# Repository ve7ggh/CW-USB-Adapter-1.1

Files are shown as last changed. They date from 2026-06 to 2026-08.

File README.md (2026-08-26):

# VE7GGH CW USB Adapter <!-- omit from toc -->

- [Instructions on How to Use](#instructions-on-how-to-use)
  - [Practice Software](#practice-software)
- [Project Structure](#project-structure)
- [Hardware](#hardware)
- [Firmware](#firmware)
- [Bootloader](#bootloader)
- [Building](#building)
  - [Hardware](#hardware-1)
  - [Firmware](#firmware-1)
  - [Bootloader](#bootloader-1)
- [Updating Firmware](#updating-firmware)
- [Licensing](#licensing)
- [Acknowledgements](#acknowledgements)
- [Author](#author)

An open-source USB CW paddle interface based on the Microchip ATSAMD21E18A microcontroller.

The adapter converts a standard Morse code paddle or straight key into a USB Human Interface Device (HID) keyboard, allowing it to work with a wide variety of amateur radio applications, Morse code trainers, and operating systems without requiring proprietary drivers.

This project is a complete open-source hardware and software design, including custom hardware, open-source firmware, a modified UF2 bootloader, manufacturing files, and documentation.

> **NOTE**: This project is an independent derivative work based on the Adafruit TRRS Trinkey open-source hardware and software ecosystem and is not affiliated with or endorsed by Adafruit Industries.
            - In honour of them this projects Bootloader and Firmware v1.x works on their hardware for half price, however if you want to support a HAM to continue inventing radio related open source devices, then I thank you for your support, it means so much to me.
            -Small batches of working v1.x are being produced. 			
             
			I am a beginner when it comes to development, still learning CW, all this was new to me 6 months ago, please accept there may be errors or conflicting information in the heavy documentation, I am learning and struggling with my own design.
			As development continues I will learn to organize as best as possible and follow version control to make things clear for the beginner to follow and contribute.
			
			Version 1.x series is proof of design utilizing 3D printed resin shell and simple updates to solve the issue of cheap chinese adapters being a waste of time and money.
				-Features added beyond basic paddle control for online/app training of CW.
                -Addded MIDI capabilities to work with FLEX Radio
				-Sublicense from Microchip inc for USB HID/VID limited to 10K units.
            Version 2.x series will change to injection molded case and be larger like USB thumb drive including protective cap and lanyard attachment.
                -Larger board for ease of manufacturing, adding improvements and reducing cost.
                -Color choices of shell, grey or transparent.
                -Switching 3.5mm jack to mid mount TRS.
                -ESD protections for microcontroller.				

---

## Instructions on How to Use

The CW USB Adapter works with Morse Code **Paddles** that use a TRS 3.5mm cable. The adapter is a plug-and-play device - no drivers need to be installed.
Wiring follows the standard: Tip (DIT), Ring (DAH), Sleeve (Ground)
Once you plug in the adapter, the paddle works like a keyboard:

* **Dits** are the Left Control (`L-Ctrl`) key
* **Dahs** are the Right Control (`R-Ctrl`) key

### Practice Software

The CW USB adapter can be used with (but is not limited to) the following web applications:
More will be added to this list once verified.

* [MoreCode.World Keyer](https://morsecode.world/international/trainer/keyer.html)
* [DiDahDit](https://didahdit.com/)
* [VBand](https://hamradio.solutions/vband/)

The CW USB adapter can also be used with Remote Flex Radio MIDI and AetherSDR (in development) Beta testing in **CWUSB firmware 1.2RC2.UF2**
Future potential for Remote ICOM 7300 testing (Advanced required in Canada for remote transmit)
---

## Project Structure

| Directory | Description |
|:---|:---|
| `/hardware` | PCB design, schematics, Gerbers, BOM, EasyEDA source |
| `/firmware` | UF2 Application firmware |
| `/bootloader` | UF2 bootloader |
| `/files` | 3D models, mechanical drawings and supporting files |

Detailed documentation is available in the README contained within each directory.

---

## Hardware

The hardware is based on the Adafruit TRRS Trinkey PCB and has been substantially redesigned.

Included are:

- EasyEDA Pro source
- Schematics
- PCB layout
- Gerbers
- BOM
- Pick-and-place files

See: [hardware/README.md](hardware/README.md)

---

## Firmware

The firmware converts paddle closures into USB HID keyboard events while providing visual feedback using the onboard RGB Led.

Features include:
- UF2 drag and drop firmware (for easy updates)
- USB HID Keyboard (simulates the device) CTRL LEFT/CTRL RIGHT
- Iambic paddle support
- NeoPixel RGB LED indicator
- Low-latency operation

See: [firmware/README.md](firmware/README.md)

---

## Bootloader

The project uses a customized version of the Adafruit UF2 SAMDx1 Bootloader.

See: [bootloader/README.md](bootloader/README.md)

---

## Building

### Hardware

Manufacture the PCB using the supplied Gerber files or open the EasyEDA Pro project for modifications.

### Firmware

Compile using:

- Arduino IDE
- PlatformIO

### Bootloader

Compile using the Adafruit UF2 SAMDx1 build environment.

---

## Updating Firmware

1. Connect the adapter via USB.
2. Double-tap the onboard Reset button.
3. The UF2 drive will appear on your computer.
4. Drag the new .uf2 firmware file onto the drive.
5. The device automatically reboots into the updated firmware.

---

## Licensing

This repository contains multiple independently licensed components.

| Component | License |
|:---|:---|
| Firmware | MIT |
| Hardware | CC BY-SA 3.0 Unported |
| Bootloader | MIT with preserved third-party notices |

See the LICENSE file within each directory for complete licensing information.

Third-party acknowledgements are contained in NOTICE.md.

---

## Acknowledgements

This project builds upon the excellent open-source work of:

- Adafruit Industries
- Microsoft
- Microchip Technology
- ARM
- Arduino
- TinyUSB contributors

Their commitment to open source has made this project possible.

---

## Author

**VE7GGH**

Open Source Canadian Amateur Radio Project

73!

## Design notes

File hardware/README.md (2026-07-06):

# Hardware

## Overview

This directory contains the complete open-source hardware design for the VE7GGH CW USB Adapter.

The design is based on the Adafruit TRRS Trinkey open-source hardware and has been substantially modified to create a board specifically intended for USB CW paddle interfacing and other USB HID applications.

The hardware has been developed to be fully reproducible. Source files and manufacturing data are included to allow others to study, modify, manufacture, and improve the design.

## Contents

This directory may contain:

- EasyEDA Pro project files
- Schematic source files
- PCB layout files
- Gerber manufacturing files
- Drill files
- Bill of Materials (BOM)
- Pick-and-Place (CPL) files
- PDF schematics
- Hardware documentation
- Images and renderings

## Derivative Design

This hardware is derived from the following open-source project:

**Adafruit TRRS Trinkey PCB**

https://github.com/adafruit/Adafruit-TRRS-Trinkey-PCB

Major modifications include:

- New PCB layout
- Redesigned board outline
- Custom silkscreen artwork
- Modified routing
- Updated component placement
- Project-specific hardware changes
- Removal of Adafruit trademarks and branding

This project is an independent derivative work and is not affiliated with, sponsored by, or endorsed by Adafruit Industries.

## Licensing

The hardware design files contained in this directory are licensed under the:

**Creative Commons Attribution-ShareAlike 3.0 Unported (CC BY-SA 3.0)**

See:

- `LICENSE` – Hardware licensing information for this project.
- `license.txt` – Original Creative Commons Attribution-ShareAlike 3.0 Unported license text as provided by the upstream Adafruit project.

## Attribution

This project gratefully acknowledges Adafruit Industries for releasing the original TRRS Trinkey hardware design as open-source hardware, making this derivative work possible.

## Manufacturing

The included manufacturing files are intended to allow fabrication of the PCB by any compatible PCB manufacturer.

Before manufacturing hardware, users should verify that the latest revision of the design is being used.

## Disclaimer

This hardware is provided "as is" without warranty of any kind. Users are responsible for verifying the design's suitability for their intended application before manufacturing or deployment.

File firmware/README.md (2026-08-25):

# Firmware <!-- omit from toc -->

- [Overview](#overview)
- [Features](#features)
- [Dependencies](#dependencies)
- [Building](#building)
  - [Requirements](#requirements)
  - [Compile](#compile)
  - [Firmware Update](#firmware-update)
- [Hardware Interface](#hardware-interface)
  - [3.5 mm TRRS Connector](#35-mm-trrs-connector)
  - [Onboard Peripherals](#onboard-peripherals)
  - [Firmware Operation](#firmware-operation)
    - [USB HID Mapping](#usb-hid-mapping)
    - [NeoPixel Status](#neopixel-status)
- [Repository Contents](#repository-contents)
- [License](#license)

## Overview

This directory contains the application firmware for the **VE7GGH CW USB Adapter**.

The firmware is written for the Microchip ATSAMD21E18A microcontroller and transforms the device into a USB Human Interface Device (HID) keyboard for use with CW iambic paddles.

When a paddle contact is closed:

- Dit → USB Keyboard Left Ctrl
- Dah → USB Keyboard Right Ctrl

This allows the adapter to work with a wide variety of Morse code training software and amateur radio applications without requiring custom drivers.

The firmware is designed to be compiled using the Arduino IDE or PlatformIO. Can generate .bin firmware, then convert to .uf2 before being drag and drop compatible.
Or upload to connected com port device on local computer with IDE, all testing done with Arduino IDE.
Or just download my firmware releases from the Github Repo.

## Features

- USB HID Keyboard device
- Low-latency paddle input
- Iambic paddle support
- MIDI device support.
- NeoPixel RGB status indicator
- Native USB support
- UF2 drag-and-drop firmware updates
- Compatible with Windows, macOS, Linux, and Android (OTG)
- Open-source firmware
- Commercial-friendly MIT licensing

## Dependencies

This firmware uses the following open-source libraries:

- Adafruit TinyUSB Library (MIT License)
- Adafruit NeoPixel Library (MIT License)
- Arduino SAMD Core

## Building

### Requirements

- Arduino IDE 2.x or PlatformIO
- Adafruit SAMD Board Package or CW USB Adapter Custom Arduino package (in development)
- TinyUSB selected as the USB Stack

### Compile

1. Open the firmware project in Arduino IDE.
2. Select the appropriate board.
3. Select **TinyUSB** as the USB Stack.
4. Verify and compile the project.

### Firmware Update

1. Connect the device to your computer.
2. Double-tap the Reset button to enter Bootloader mode.
3. A USB drive will appear.
4. Copy the compiled `.uf2` firmware file onto the drive.
5. The device will automatically reboot with the updated firmware.

No external programmer is required for normal firmware updates.

## Hardware Interface

### 3.5 mm TRRS Connector

| Function | Contact | Arduino Pin | MCU Pin |
| :-- | :-- | :-- | :-- |
| Dit | Tip | PIN_TIP | PA04 |
| Dah | Ring 1 | PIN_RING1 | PA09 |
| Ground (Compatibility) | Ring 2 | PIN_RING2 | PA08 |
| Ground | Sleeve | PIN_SLEEVE | PA05 |
| For maximum compatibility with standard 3-conductor (TRS) paddle cables, the firmware actively drives both Ring 2 and Sleeve LOW to provide a common ground. |

### Onboard Peripherals

| Peripheral | Arduino Pin | MCU Pin |
| :-- | :-- | :-- |
| NeoPixel RGB LED | PIN_NEOPIXEL | PA01 |
| Native USB | — | PA24 / PA25 |

###  Firmware Operation

#### USB HID Mapping
| Paddle | USB Output |
| :-- | :-- |
| Dit | Left Ctrl |
| Dah | Right Ctrl |

#### NeoPixel Status

| State | LED Color |
| :-- | :-- |
| Idle | **Dim** Blue |
| Dit Pressed | **Green** |
| Dah Pressed | **Amber** |
| Both Paddles Pressed | **Purple** |
| Bootloader Mode | **Green** (UF2 Bootloader) |

## Repository Contents

This directory typically contains:

- Arduino source code
- Project configuration files
- Firmware documentation
- Release firmware (.uf2)
- Commercial Use
- This firmware is licensed under the MIT License.

You are free to:

- Use
- Modify
- Redistribute
- Manufacture products
- Sell products
- Create derivative works provided the original copyright notice and license are retained.

## License

The firmware contained in this directory is licensed under the MIT License.

See:

LICENSE — Firmware License
Author
VE7GGH

Open Source Canadian Amateur Radio Project

73!

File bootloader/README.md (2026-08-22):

# Bootloader

## Overview

This directory contains a customized version of the **Adafruit UF2 SAMDx1 Bootloader** specifically configured for the **VE7GGH CW USB Adapter**.

The UF2 bootloader provides a robust system for firmware updates, including:
- **Drag-and-Drop Updates**: Appears as a USB Mass Storage drive for easy .uf2 file deployment.
- **Resiliency**: Support for double-tap reset to enter bootloader mode.
- **Board Identification**: Correct USB descriptors and branding for this hardware.
- **Native USB**: No external hardware programmers (like J-Link) are required for standard updates.

## Upstream Project

This bootloader is a derivative work of the Adafruit UF2 SAMDx1 project:
[https://github.com/adafruit/uf2-samdx1](https://github.com/adafruit/uf2-samdx1)

We gratefully acknowledge the work of Microsoft Corporation, Adafruit Industries, and the community contributors who maintain the UF2 project.

## Project Modifications

This version includes board-specific changes for the CW USB Adapter hardware including:
- Custom Pin mappings and LED behaviors.
- Board-specific USB VID/PID and Strings.
- Optimized build configurations for the ATSAMD21E18A.
- USB Architecture & Microchip Sublicensed Identity
- USB Vendor ID (VID): 0x04D8 (Microchip Technology Inc. sublicensed tier)
- USB Product ID (PID): 0xE417
- Product Name: VE7GGH CW Adapter
- Manufacturer: VE7GGH

## Licensing

This project is open-source. Due to the nature of embedded bootloaders, it incorporates code under several licenses.

- **This Derivative Work**: Licensed under the **MIT License**. See [LICENSE.md](LICENSE.md).
- **Original UF2 Code**: Licensed by Microsoft and Adafruit under the **MIT License**. See [LICENSE-MIT.txt](LICENSE-MIT.txt).
- **Third-Party Components**: Includes hardware-layer code from Atmel (Microchip) and ARM. Original licenses and notices are preserved in [THIRD-PARTY-NOTICES.txt](THIRD-PARTY-NOTICES.txt).

## Building and Flashing

For instructions on how to compile this bootloader and flash it to bare-metal hardware via SWD, please refer to the documentation in the `/Documentation` directory or the original upstream repository.

## Disclaimer

This project is an independent work and is not affiliated with, sponsored by, or endorsed by Adafruit Industries.

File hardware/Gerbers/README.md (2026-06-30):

VE7GGH 2026
An isssue was discovered with the RST line for BOOT button being shorted or pulled low that would not allow communication with Microcontroller. Button datasheet did not confirm conductor path is corner to corner on SMD button, not directly across, trace was modified and will be fixed in V1.2 copper.
I will try and remember a MOD document

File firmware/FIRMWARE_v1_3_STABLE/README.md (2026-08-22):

# VE7GGH CW USB Adapter — v1.3 → v1.3STABLE Improvements

## Summary
This update improves firmware robustness and USB HID efficiency without changing pin mapping, USB VID/PID, or NeoPixel color scheme. All changes are backward-compatible with the original v1.3 Stable design.

## Changes

### 1. Real Debounce Logic
- **Before:** A blind `delay(10)` at the end of `loop()` was labeled "Debounce / Polling" but performed no actual debounce.
- **After:** Each paddle input now requires `DEBOUNCE_MS` (default 5 ms) of continuous stability before a state change is accepted, using `millis()`-based timing.

### 2. Non-Blocking Polling
- **Before:** `delay(10)` blocked the entire loop every cycle.
- **After:** Polling interval (`POLL_INTERVAL_MS`, default 2 ms) is handled via `millis()` comparison, keeping the loop responsive and non-blocking.

### 3. Stuck-Key Fail-Safe
- **New:** If a paddle contact remains closed longer than `STUCK_KEY_MS` (default 4000 ms) — e.g. due to a short, moisture, or mechanical failure — the corresponding modifier key is automatically released to prevent an indefinitely "stuck" Ctrl key on the host system.

### 4. Bounded USB Enumeration Wait
- **Before:** `while (!TinyUSBDevice.mounted()) delay(1);` could hang forever in `setup()` if USB enumeration failed.
- **After:** Wait is capped at `USB_MOUNT_TIMEOUT_MS` (default 3000 ms). On timeout, the NeoPixel flashes red twice as a visual error indicator, then `setup()` continues (the main loop still won't send HID reports until `usb_hid.ready()` is actually true).

### 5. Reduced Redundant HID Traffic
- **Before:** A full HID keyboard report was sent every loop cycle (every ~10 ms), regardless of whether the key state changed.
- **After:** A report is only sent when the modifier byte actually changes (`lastModifier` tracking), reducing unnecessary USB traffic.

### 6. Centralized Timing Constants
- All tunable timing values are now grouped under a single `// ── Timing (tune here) ──` block:
  - `DEBOUNCE_MS`
  - `STUCK_KEY_MS`
  - `POLL_INTERVAL_MS`
  - `USB_MOUNT_TIMEOUT_MS`

## Unchanged
- Pin mapping (`DIT_PIN`, `DAH_PIN`, `GND_COMP_PIN`, `GND_MAIN_PIN`)
- USB VID/PID (`0x04D8` / `0xE417`)
- NeoPixel idle/dit/dah/both color scheme
- Overall program structure and license (MIT)

## Not Yet Implemented (Future Considerations)
- Hardware watchdog timer (SAMD21 WDT) as an additional lockup guard.
- Configurable debounce/timeout values via a settings file or serial command interface.
- Return-value checking on `usb_hid.begin()` / `pixel.begin()` for init-failure indication.

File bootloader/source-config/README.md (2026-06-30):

Custom UF2 Bootloader Implementation
For this project, I have implemented a custom, branded UF2 bootloader based on the adafruit/uf2-samdx1 (v4.0.0) source. This allows for seamless "drag-and-drop" firmware updates via a USB mass storage drive, tailored specifically for the VE7GGH CW Adapter hardware.

Key Accomplishments:
Custom Branding: Fully localized the bootloader identity. When in bootloader mode, the device identifies as "VE7GGH CW Adapter" (Model) and mounts a drive named "CWUSBUPDATE". The INFO_UF2.TXT file includes a direct link to this GitHub repository.
Hardware Compatibility: Configured for the SAMD21E18A MCU in a crystal-less internal oscillator configuration, ensuring high reliability on custom PCB layouts without external clock requirements.
Code-Size Optimization: To fit the full feature set within the strict 8KB bootloader protection region, I performed manual code-squeezing by disabling non-essential bootloader features (WebUSB, HID-extension, and Handover protocols). This avoided the use of unstable Link Time Optimization (LTO), ensuring robust USB enumeration across all operating systems.
Safety & Persistence: Implemented hardware-level flash protection (NVMCTRL_BOOTPROT) for the first 8KB. This ensures the bootloader cannot be accidentally overwritten or corrupted during normal application firmware updates.
Technical Details:
Target MCU: ATSAMD21E18A
Bootloader Size: 8KB (8192 bytes)
USB Drive Label: CWUSBUPDATE
Build Environment: Compiled with arm-none-eabi-gcc on Linux Mint.
Programming Interface: Verified flashing and fuse configuration via Atmel-ICE and SWD.

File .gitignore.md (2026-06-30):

# --- OS Specific ---
.DS_Store
Thumbs.db
*.swp

# --- Arduino/PlatformIO ---
bin/
obj/
*.elf
*.hex
libdeps/
.pio/
.vscode/
build/
*.gen.h

# --- EasyEDA / CAD ---
# We want to keep the .epro and Gerbers, but ignore local backups if they exist
*.log
*.bak

# --- Bootloader Build Artifacts ---
# We keep the final binaries in your /binaries folder, 
# but we ignore the intermediate objects created during a local 'make'
bootloader/builds/
*.o
*.d
*.map

# --- Python/Misc ---
__pycache__/
*.pyc

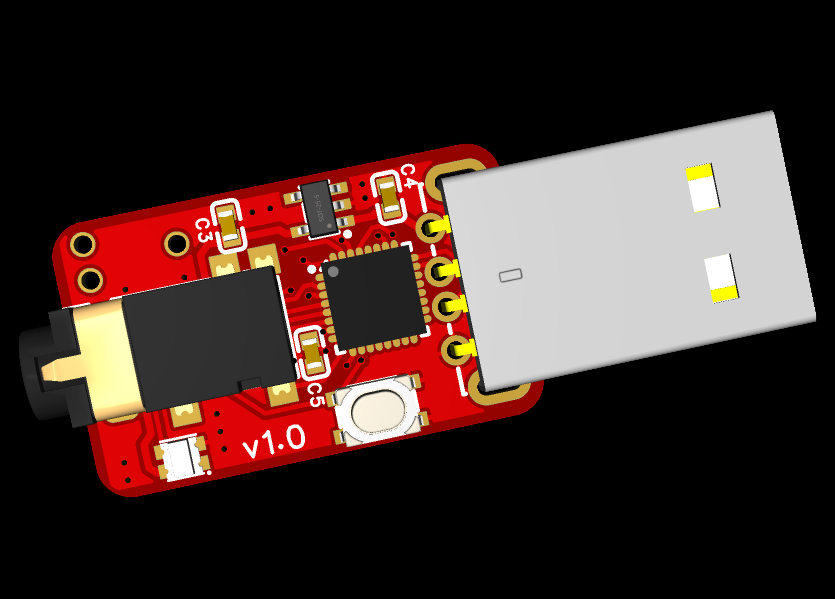
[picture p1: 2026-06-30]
hardware/Images/Screenshot 2026-05-29 085627.png

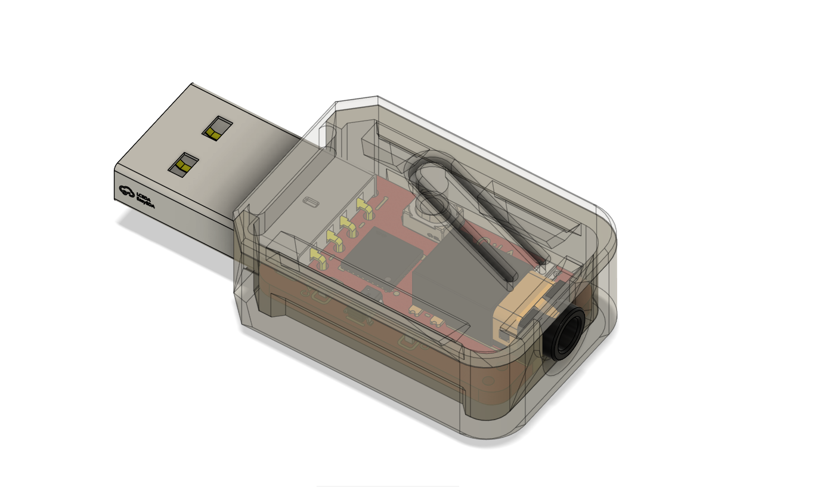
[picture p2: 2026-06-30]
hardware/Images/Screenshot 2026-06-29 175539.png

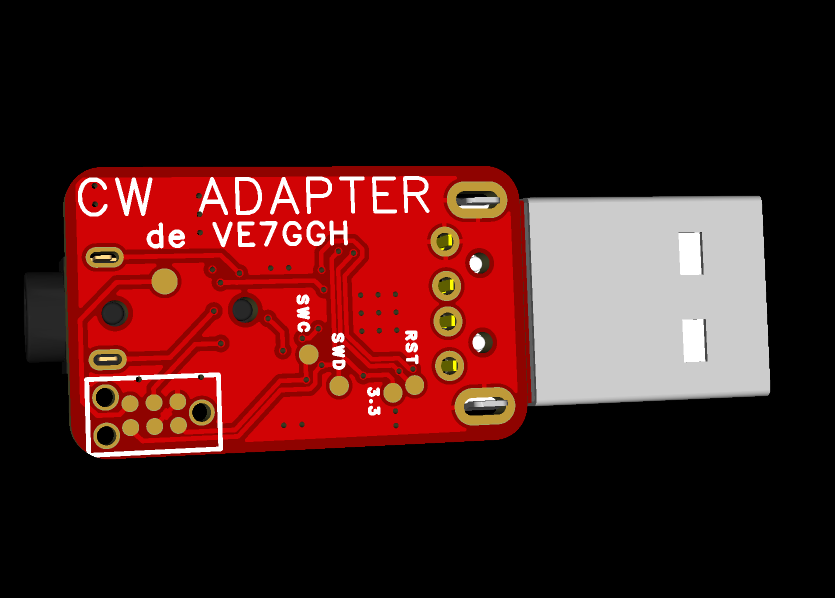
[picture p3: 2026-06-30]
hardware/Images/Screenshot 2026-05-29 085713.png

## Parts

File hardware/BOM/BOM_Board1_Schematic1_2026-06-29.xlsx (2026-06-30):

No. | Quantity | Comment | Designator | Footprint | Value | Manufacturer Part | Manufacturer | Supplier Part | Supplier | Device | Name | Description | drawing:Version
1 | 2 | 1uF | C3,C4 | C0603 | 1uF | CC0603KRX5R6BB105 | YAGEO(国巨) | C106214 | LCSC | CC0603KRX5R6BB105 | 1uF | Capacitance:1uF Tolerance:±10% Tolerance:±10% Voltage Rating:10V Temperature Coefficient:X5R | V1.0
2 | 1 | 1uF | C5 | C0603 | 1uF | CC0603KRX7R9BB105 | YAGEO(国巨) | C559769 | LCSC | CC0603KRX7R9BB105 | 1uF | Capacitance:1uF Tolerance:±10% Tolerance:±10% Voltage Rating:50V Temperature Coefficient:X7R | V1.0
3 | 1 | PJ-332A-6A | CN1 | AUDIO-SMD_PJ-332A-6A |  | PJ-332A-6A | 韩国韩荣 | C2848643 | LCSC | PJ-332A-6A | PJ-332A-6A | Connector Type:3.5mm Headphone Jack Current Rating:1A Voltage Rating (Max):30V Operating Temperature:-25℃~+80℃ Operating Temperature:-25℃~+80℃ | V1.0
4 | 1 | WS2812B-2020 | LED2 | LED-SMD_4P-L2.0-W2.0-TL_WS2812B-2020 |  | WS2812B-2020 | worldsemi | C965555 | LCSC | WS2812B-2020 | WS2812B-2020 | Wavelength:515.6nm；622.5nm；470.4nm Luminous Intensity:200mcd；160mcd；520mcd Fixed-Frequency Pwm Mode:- Data Transmission Rate:100KB/S Voltage - Supply:5V Voltage - Supply:5V Quiescent Current:- Lens Color:- ESD Withstand Voltage:- Installation method:op Vi | V1.0
5 | 1 | SKRPACE010 | SW1 | KEY-SMD_4P-L4.2-W3.2-P2.20-LS4.6 |  | SKRPACE010 | ALPSALPINE(阿尔卑斯阿尔派) | C139797 | LCSC | SKRPACE010 | SKRPACE010 | Circuit:SPST Actuator Style:Oval Button Mounting Type:Surface Mount,Vertical Length:4.2mm Width:3.2mm Switch Height:2.5mm Contact Current:50mA Voltage Rating:16V With Lamp:- Life:- | V1.0
6 | 1 | ATSAMD21E18A-MUT | U1 | QFN-32_L5.0-W5.0-P0.50-TL-EP3.6 |  | ATSAMD21E18A-MUT | MICROCHIP(美国微芯) | C2052801 | LCSC | ATSAMD21E18A-MUT | ATSAMD21E18A-MUT | CPU Core:ARM Cortex-M0+ CPU Maximum Speed:48MHz Core Size:32 Bit Program Storage Size:256KB Program Memory Type:FLASH RAM Size:32KB EEPROM:- Number of I/O:26 ADC (Bit):12bit DAC (Bit):10bit Oscillator Type:Built-in Voltage - Supply:1.62V~3.6V Voltage - Su | V1.0
7 | 1 | AP7365-33WG-7 | U2 | SOT-25_L3.0-W1.6-P0.95-LS2.8-BR |  | AP7365-33WG-7 | DIODES(美台) | C150742 | LCSC | AP7365-33WG-7 | AP7365-33WG-7 | Output Type:Fixed Voltage - Supply:6V Output Voltage:3.3V Output Voltage:3.3V Output Current:600mA Power Supply Rejection Ratio (PSRR):65dB@(1kHz) Voltage Dropout:400mV@(600mA) standby current:300uA Features:Short Circuit Protection；Over Temperature Prote | V1.0
8 | 1 | TC2030_-MCP-NL | U3 | TC2030 |  |  |  |  |  | TC2030_-MCP-NL |  |  | V1.0
9 | 1 | USB-05 | USB | USB-A-TH_USB-05 |  | USB-05 | SOFNG(硕方) | C112454 | LCSC | USB-05 | USB-05 | Connector Type:Type-A Protocol Standard:USB 2.0 Gender:Male Mounting Type:Right Angle Number of Contacts:4P Number of Ports:1 Current Rating-Power:1A Voltage Rating:24V Length:18.75mm Operating Temperature:-35℃~+75℃ Operating Temperature:-35℃~+75℃ | V1.0

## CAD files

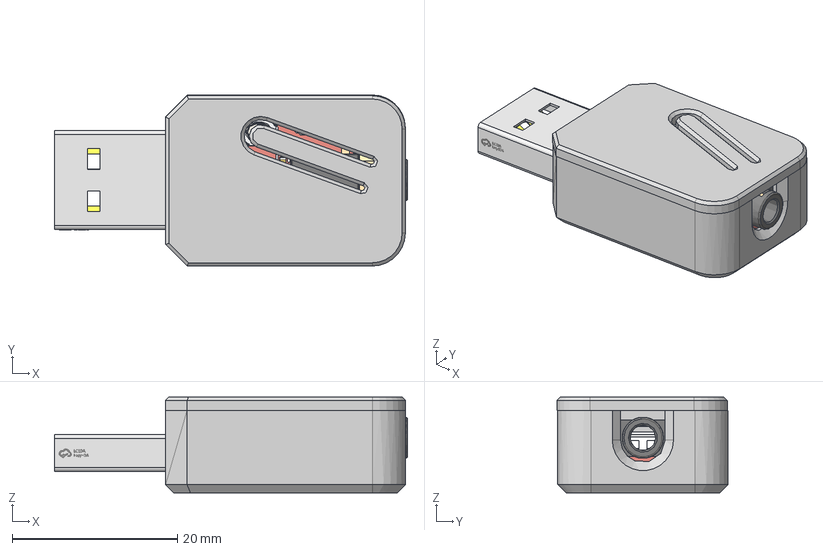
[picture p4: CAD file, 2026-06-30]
files/3D/CW USB V2 ASSEMBLY.step
42.7 x 20.7 x 11.6 mm

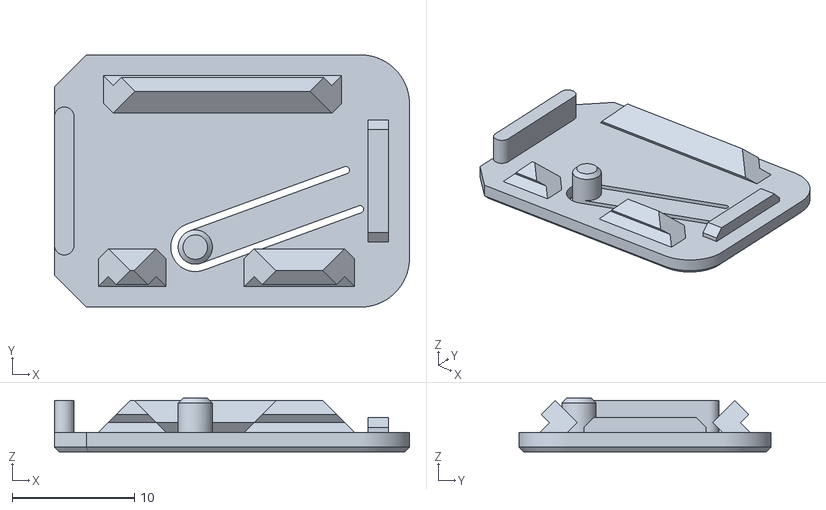
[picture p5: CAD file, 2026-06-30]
files/3D/CW USB Case Top V2.stl
29.0 x 20.6 x 4.40

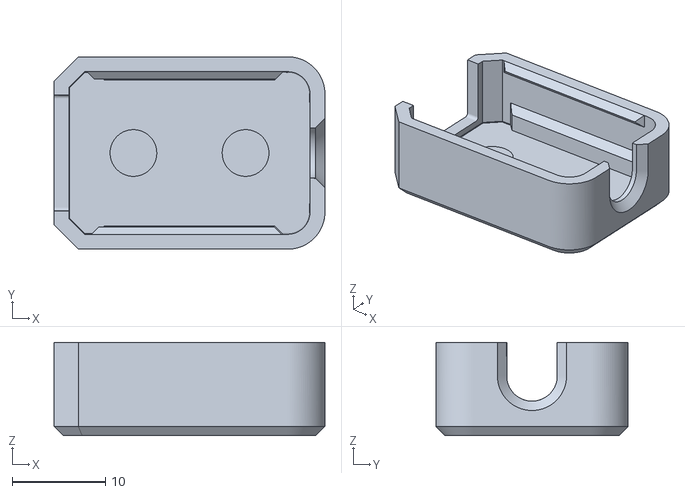
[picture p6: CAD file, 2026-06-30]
files/3D/CW USB Case bottom V2.stl
29.0 x 20.6 x 10.0

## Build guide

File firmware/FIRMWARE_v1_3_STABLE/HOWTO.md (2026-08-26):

# VE7GGH CW USB Adapter — User Features and Firmware Configuration

## Overview

The VE7GGH CW USB Adapter connects an iambic CW paddle to a computer as a standard USB HID keyboard. It converts the **Dit** paddle contact to **Left Ctrl** and the **Dah** contact to **Right Ctrl**, allowing compatible CW practice, and web keyer software to receive direct paddle input. A growing list of compatibility is being listed in the main project README.

## Features and Benefits

### Driverless USB HID operation

The adapter presents itself as a standard USB keyboard.

**Benefit:** It is intended to work without installing a dedicated driver on operating systems that support USB HID keyboards.

### Direct paddle-to-keyboard mapping

- **Dit (Tip):** Left Ctrl
- **Dah (Ring 1):** Right Ctrl

**Benefit:** CW applications that accept separate left and right modifier-key inputs can use the paddle directly.

### TRS and TRRS paddle-plug support

The firmware configures both the Ring 2 and Sleeve contacts as low-level ground references.

**Benefit:** This supports the adapter’s intended use with both standard 3.5 mm TRS stereo plugs and TRRS plugs, subject to the paddle cable’s wiring matching the stated pin mapping.

### Contact debounce

The firmware reads paddle inputs at a short polling interval and accepts an input change only once the contact has remained stable for the configured debounce time.

**Benefit:** Helps suppress false transitions caused by mechanical contact bounce.

### Stuck-key safety release

If a paddle input remains active longer than the configured stuck-key timeout, the firmware releases that key state.

**Benefit:** Reduces the risk that a contaminated contact, cable fault, or accidental short leaves Ctrl held continuously on the host computer.

### NeoPixel status indication

| Adapter state | NeoPixel color |
|---|---|
| Idle / ready | Dim blue |
| Dit active | Green |
| Dah active | Amber |
| Both paddles active | Purple |
| USB connection success during startup | White flash |
| USB mount timeout | Red blink |

**Benefit:** Provides immediate visual confirmation of paddle activity and startup state.

### Bounded USB mount wait

At startup, the firmware waits for USB enumeration only for the configured timeout rather than waiting indefinitely.

**Benefit:** Avoids a permanent startup hang if a host does not enumerate the device promptly.

### Efficient HID reporting

The firmware sends a HID keyboard report only when the modifier-key state changes.

**Benefit:** Avoids redundant USB reports while retaining normal paddle response.

## Firmware Configuration

The configuration values below are located near the top of `FIRMWARE_v1_3_STABLE.ino`. Edit them in the Arduino IDE, then compile and upload the firmware.

### Change Dit/Dah keyboard mapping

The default key mappings are:

```cpp
#define DIT_MODIFIER  KEYBOARD_MODIFIER_LEFTCTRL
#define DAH_MODIFIER  KEYBOARD_MODIFIER_RIGHTCTRL
```

To reverse the output mapping, use:

```cpp
#define DIT_MODIFIER  KEYBOARD_MODIFIER_RIGHTCTRL
#define DAH_MODIFIER  KEYBOARD_MODIFIER_LEFTCTRL
```

This changes which Ctrl key the firmware reports for each paddle input. It does not alter the physical wiring of the Tip and Ring 1 contacts.

### Use different modifier keys

For software configured to use Shift or Alt, change the mapping constants. For example:

```cpp
// Shift mapping
#define DIT_MODIFIER  KEYBOARD_MODIFIER_LEFTSHIFT
#define DAH_MODIFIER  KEYBOARD_MODIFIER_RIGHTSHIFT
```

```cpp
// Alt mapping
#define DIT_MODIFIER  KEYBOARD_MODIFIER_LEFTALT
#define DAH_MODIFIER  KEYBOARD_MODIFIER_RIGHTALT
```

Confirm that the target application supports the selected key combination before using a custom mapping.

### Adjust debounce, polling, and safety timing

```cpp
#define DEBOUNCE_MS          5
#define STUCK_KEY_MS         4000
#define POLL_INTERVAL_MS     2
#define USB_MOUNT_TIMEOUT_MS 3000
```

| Setting | Default | Meaning | Typical adjustment |
|---|---:|---|---|
| `DEBOUNCE_MS` | 5 ms | Time a contact must remain stable before being accepted | Lower values may feel more immediate but can admit bounce; higher values can help noisy contacts. |
| `STUCK_KEY_MS` | 4000 ms | Continuous active time before the firmware releases a paddle state | Increase only if a legitimate use case needs a very long continuous hold. |
| `POLL_INTERVAL_MS` | 2 ms | Interval between paddle scans | Keep low for responsive operation; increasing it reduces scan frequency. |
| `USB_MOUNT_TIMEOUT_MS` | 3000 ms | Maximum startup wait for USB mounting | Increase if a particular host consistently needs more time to enumerate the device. |

### Change NeoPixel brightness

In `setup()`, locate:

```cpp
pixel.setBrightness(80);
```

Use a value from `0` to `255`:

- `0`: off
- Lower values: dimmer
- Higher values: brighter

### Change NeoPixel colors

The color definitions use `pixel.Color(red, green, blue)`, with each RGB channel normally ranging from `0` to `255`.

```cpp
#define COLOR_IDLE   pixel.Color(0,   0,   20)
#define COLOR_DIT    pixel.Color(0,   80,  0)
#define COLOR_DAH    pixel.Color(80,  40,  0)
#define COLOR_BOTH   pixel.Color(80,  0,   80)
```

For example, a red idle state could be defined as:

```cpp
#define COLOR_IDLE pixel.Color(20, 0, 0)
```

## Uploading Modified Firmware

1. Open `FIRMWARE_v1_3_STABLE.ino` in Arduino IDE 1.8.13+ or Arduino IDE 2.x.
2. Select the appropriate SAMD21 board target. Custom CW Adapter target coming late 2026 to Github.
3. Select **Tools → USB Stack → TinyUSB**.
4. If necessary, double-tap the adapter’s reset button to enter bootloader mode.
5. Select the appropriate port and choose **Upload**.
6. Confirm the startup white flash and idle blue status after the device enumerates.

## Important Notes

- Keep the USB VID/PID values aligned with the applicable bootloader and board configuration.
- Changes to modifier keys can affect normal keyboard shortcuts on the host. Test with a CW application before general desktop use.
- The firmware is designed as a paddle-to-HID adapter. It does not itself generate iambic timing, decode Morse, or provide an onboard WPM setting.

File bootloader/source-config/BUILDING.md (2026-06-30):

# Building the Custom UF2 Bootloader

This document describes how to build the custom UF2 bootloader for the VE7GGH CW Adapter, based on the Adafruit `uf2-samdx1` bootloader (v4.0.0).

## Overview

A custom bootloader was created to provide

- Custom USB product name VE7GGH CW Adapter
- Custom UF2 drive label CWUSBUPDATE
- Custom board identification
- Custom GitHub support URL
- Native UF2 drag-and-drop firmware updates
- Full compatibility with the ATSAMD21E18A MCU

The hardware is electrically identical to the Adafruit TRRS Trinkey M0.

---

# Development Environment

Operating System

- Linux Mint

Compiler

- arm-none-eabi-gcc 13.2.1

Source

- Adafruit `uf2-samdx1`
- Version v4.0.0

---

# Installing Build Tools

```bash
sudo apt update
sudo apt install git make python3 gcc-arm-none-eabi binutils-arm-none-eabi
```

Verify the compiler

```bash
arm-none-eabi-gcc --version
```

---

# Download the Source

```bash
git clone --branch v4.0.0 httpsgithub.comadafruituf2-samdx1
cd uf2-samdx1
git submodule update --init --recursive
```

---

# Create the Custom Board

Copy the TRRS Trinkey board configuration.

```bash
cp -r boardstrrs_trinkey_m0 boardsve7ggh_cw_adapter
```

Edit

```
boardsve7ggh_cw_adapterboard_config.h
```

Update the branding information.

Example

```c
#define VENDOR_NAME    VE7GGH
#define PRODUCT_NAME   VE7GGH CW Adapter
#define VOLUME_LABEL   CWUSBUPDATE
#define INDEX_URL      httpsgithub.comve7gghCWUSB-Adapter
#define BOARD_ID       SAMD21E18A-CWUSB-v1
```

---

# board.mk

The custom board uses the original board definition.

```
CHIP_FAMILY = samd21
CHIP_VARIANT = SAMD21E18A
```

---

# Source Code Patch

The standard Adafruit source hard-codes several optional features.

To allow these features to be disabled from the build system, the following
definitions in `incuf2.h` were modified.

Change

```c
#define USE_WEBUSB 1
```

to

```c
#ifndef USE_WEBUSB
#define USE_WEBUSB 1
#endif
```

Change

```c
#define USE_HID_EXT 1
```

to

```c
#ifndef USE_HID_EXT
#define USE_HID_EXT 1
#endif
```

Change

```c
#define USE_HID_HANDOVER 1
```

to

```c
#ifndef USE_HID_HANDOVER
#define USE_HID_HANDOVER 1
#endif
```

Change

```c
#define USE_MSC_HANDOVER 1
```

to

```c
#ifndef USE_MSC_HANDOVER
#define USE_MSC_HANDOVER 1
#endif
```

These changes allow compiler command-line overrides.

---

# Makefile.user

Create a file named

```
Makefile.user
```

Contents

```make
BOARD=ve7ggh_cw_adapter

BLD_EXTA_FLAGS=-DUSE_WEBUSB=0 
               -DUSE_HID_EXT=0 
               -DUSE_HID_HANDOVER=0 
               -DUSE_MSC_HANDOVER=0
```

This disables optional bootloader features that are not required by this
project while preserving normal UF2 functionality.

No Link Time Optimization (LTO) is used.

---

# Building

Compile using

```bash
make clean
make
```

A successful build reports approximately

```
Space left 460
```

---

# Output Files

Compiled files are located in

```
buildve7ggh_cw_adapter
```

Important files

```
bootloader-ve7ggh_cw_adapter-v4.0.0+.bin
```

Used to flash a blank ATSAMD21E18A using SWD.

```
update-bootloader-ve7ggh_cw_adapter-v4.0.0+.uf2
```

Used to update an existing UF2 bootloader.

---

# Verifying the Build

Check the embedded strings

```bash
strings buildve7ggh_cw_adapterbootloader-ve7ggh_cw_adapter-v4.0.0+.bin  
grep -E VE7GGHCWUSBgithub
```

Expected output includes

```
VE7GGH
VE7GGH CW Adapter
CWUSBUPDATE
Model VE7GGH CW Adapter
Board-ID SAMD21E18A-CWUSB-v1
httpsgithub.comve7gghCWUSB-Adapter
```

---

# Programming

Program the `.bin` file using an Atmel-ICE (or compatible SWD programmer).

Recommended sequence

1. Set `NVMCTRL_BOOTPROT` to 0 Bytes
2. Perform Chip Erase
3. Program the bootloader
4. Verify
5. Set `NVMCTRL_BOOTPROT` to 8192 Bytes
6. Power cycle the board

---

# USB Enumeration

After programming

The board should enumerate as

```
VE7GGH CW Adapter
```

The UF2 drive should appear as

```
CWUSBUPDATE
```

The `INFO_UF2.TXT` file contains

- Model name
- Board ID
- GitHub project URL

---

# Design Notes

The original attempt used GCC Link Time Optimization (`-flto`) to reduce code
size enough to fit inside the 8 KB bootloader region.

Although this produced a binary that fit, USB enumeration became unreliable.

The final solution was to disable several optional bootloader features instead
of relying on LTO.

Disabled features

- WebUSB
- Extended HID commands
- HID handover
- MSC handover

This reduced the bootloader size sufficiently while maintaining reliable USB
operation and UF2 drag-and-drop firmware updates.

The HID keyboard functionality of the application firmware is completely
unaffected because these changes apply only to the bootloader.

---

# Repository

Project

httpsgithub.comve7gghCWUSB-Adapter

Bootloader Base

httpsgithub.comadafruituf2-samdx1

Version

v4.0.0

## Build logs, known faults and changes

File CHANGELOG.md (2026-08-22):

# Changelog

All notable changes to the VE7GGH CW Adapter project will be documented in this file.

The format is based on [Keep a Changelog](https://keepachangelog.com/en/1.1.0/).

---

## [1.0.0] - 2026-06

### Added

- Initial public release of the VE7GGH CW Adapter project.
- Custom UF2 bootloader based on Adafruit `uf2-samdx1` v4.0.0.
- Support for the ATSAMD21E18A microcontroller.
- Custom board definition `ve7ggh_cw_adapter`.
- Custom USB product name:
  - `VE7GGH CW Adapter`
- Custom UF2 drive label:
  - `CWUSBUPDATE`
- Custom board identifier:
  - `SAMD21E18A-CWUSB-v1`
- Custom `INFO_UF2.TXT` containing the project GitHub URL.
- Linux Mint build environment documentation.
- Complete build instructions.
- SWD programming procedure.
- GitHub repository documentation.

### Changed

- Created a dedicated board configuration derived from the Adafruit TRRS Trinkey M0.
- Updated bootloader branding from Adafruit to VE7GGH.
- Replaced default USB identification strings with project-specific branding.
- Updated repository URL embedded within the bootloader.

### Fixed

- Corrected FAT volume label length to comply with the FAT filesystem's 11-character maximum.
- Resolved bootloader size overflow beyond the 8 KB bootloader region.
- Eliminated unreliable USB enumeration caused by GCC Link Time Optimization (`-flto`).
- Restored reliable USB enumeration by disabling optional bootloader features instead of using LTO.
- Successfully compiled within the 8192-byte bootloader limit with approximately 460 bytes remaining.

### Technical

Modified `inc/uf2.h` to allow build-time feature overrides using compiler definitions.

Wrapped the following feature definitions with `#ifndef` guards:

- `USE_WEBUSB`
- `USE_HID_EXT`
- `USE_HID_HANDOVER`
- `USE_MSC_HANDOVER`

Added build-time overrides through `Makefile.user`:

- Disabled WebUSB.
- Disabled HID Extended commands.
- Disabled HID handover.
- Disabled MSC handover.

These changes reduce code size while preserving:

- UF2 drag-and-drop firmware updates.
- USB Mass Storage support.
- Stable USB enumeration.

### Verified

Successfully tested:

- Linux Mint build environment.
- GCC ARM Embedded 13.2.1.
- Atmel-ICE programming via SWD.
- Bootloader flashing and verification.
- USB enumeration under Windows.
- Custom USB product name.
- Custom UF2 volume label.
- Custom `INFO_UF2.TXT` contents.
- Protection of the bootloader region using `NVMCTRL_BOOTPROT`.

---

## Future

Planned improvements include:

- Assignment of a dedicated USB VID/PID.
- Additional MIDI control to be compatible with FlexRadio controls.
- Automated patching of `uf2.h` during the build process.
- Continuous Integration (CI) builds using GitHub Actions.
- Automated release generation with pre-built bootloader binaries.
- Additional firmware examples and documentation.

## Release Candidate 1.2 July 5, 2026
[1.2 RC2] — 2026-07-05
Added
- USB MIDI interface — device now enumerates as both a USB HID Keyboard and a USB MIDI device simultaneously (no drivers required)
- MIDI Note On/Off for Dit and Dah paddle inputs (default: Dit = Note 20, Dah = Note 21)
- Three operating modes: HID Only, MIDI Only, HID + MIDI (Both)
- Flash persistence via FlashStorage_SAMD — operating mode and MIDI note assignments survive power cycles
- Serial CLI over USB virtual COM port with the following commands:
help — list available commands
status — show current mode, MIDI notes, and live paddle pin states
mode [hid|midi|both] — change operating mode at runtime
midi_notes — display current MIDI note assignments
set_notes <dit> <dah> — reassign MIDI notes (0–127)
save — persist current settings to flash
reset — restore factory defaults and save
- USB device descriptors — manufacturer set to VE7GGH, product set to CW USB Adapter
- Startup double-flash (white) on NeoPixel to confirm successful boot
- Serial welcome banner printed on first Serial connection
- Full status dump printed to Serial on boot

Changed
- Loop polling delay reduced from 10 ms to 5 ms for improved responsiveness
- HID ready() check replaced with non-blocking logic
- NeoPixel color macros replaced with inline pixel.Color() calls to avoid macro expansion conflicts
- Code refactored into modular functions with explicit forward declarations
- FlashStorage_SAMD read() call corrected to pass struct by reference (required by library v1.3.2+)
- Dependencies Added
- FlashStorage_SAMD v1.3.2 or later

Compatible Software
- HID mode: Morse Code World, VBand, DitDahDit, any CW keyboard app
- MIDI mode: FlexRadio / NetKeyer, any MIDI-capable CW application

# Changelog — VE7GGH CW USB Adapter (v1.3 Stable Release) Aug 2026

## Release Overview

**VE7GGH CW USB Adapter v1.3 Stable** is a dedicated, production-ready USB HID keyboard adapter for CW iambic morse paddles. It provides clean, ultra-low latency keying without the added complexity or resource overhead of MIDI, Serial CLI parsers, or flash storage writes.

This release formally establishes custom USB identification under a sublicensed Vendor ID and Product ID from Microchip Technology Inc.

---

## [v1.3 Stable] — Hardware Identity & Production Baseline

### USB Architecture & Microchip Sublicensed Identity
- **USB Vendor ID (VID)**: `0x04D8` (Microchip Technology Inc. sublicensed tier)
- **USB Product ID (PID)**: `0xE417`
- **Product Name**: `VE7GGH CW Adapter`
- **Manufacturer**: `VE7GGH`
- **USB Stack**: Adafruit TinyUSB (`-DUSE_TINYUSB`)
- Synchronized VID/PID with the companion SAMD21 UF2 bootloader (`board_config.h`).
- Corrected TinyUSB startup sequencing: `usb_hid.begin()` and descriptor registration are finalized before bus re-attachment (`TinyUSBDevice.attach()`), guaranteeing clean plug-and-play enumeration on Windows, Linux, and macOS.

### Pure HID Keyboard Engine
- Dedicated keypress translation:
  - **Dit Contact** (Tip) $
ightarrow$ `Left Ctrl` (`KEYBOARD_MODIFIER_LEFTCTRL`)
  - **Dah Contact** (Ring 1) $
ightarrow$ `Right Ctrl` (`KEYBOARD_MODIFIER_RIGHTCTRL`)
- **Differential HID Reporting**: Transmits USB HID keyboard reports strictly when paddle state changes (`modifier != last_modifier`), drastically reducing USB bus traffic while preserving immediate sub-millisecond response.
- Excludes MIDI engine and Serial CLI parser to keep firmware footprint small, deterministic, and free of dynamic memory churn.

### Hardware & Jack Compatibility
- **Microcontroller**: Microchip SAMD21E18A (ARM Cortex-M0+ @ 48 MHz).
- **Jack Interface**: TRRS 3.5mm jack with automatic TRS stereo plug compatibility:
  - Tip (`PIN_TIP` / GPIO 0): Dit input (Internal Pull-Up)
  - Ring 1 (`PIN_RING1` / GPIO 2): Dah input (Internal Pull-Up)
  - Ring 2 (`PIN_RING2` / GPIO 4): Driven active `LOW`
  - Sleeve (`PIN_SLEEVE` / GPIO 5): Driven active `LOW`
- **Visual Feedback (NeoPixel on PIN_PA01)**:
  - Idle: Dim Blue (`(0, 0, 20)`)
  - Dit Active: Solid Green (`(0, 80, 0)`)
  - Dah Active: Solid Amber (`(80, 40, 0)`)
  - Both Active: Solid Purple (`(80, 0, 80)`)
  - Startup: White indicator flash upon host USB enumeration.

---

## Version Lineage Summary

| Version | Branch / Target | Key Changes |
| :--- | :--- | :--- |
| **v1.0 / v1.1** | Prototype | Initial proof of concept on Adafruit TRRS Trinkey hardware. |
| **v1.2 RC** | Experimental | Added experimental USB MIDI, Serial CLI configuration, and `FlashStorage_SAMD`. |
| **v1.3 Stable** *(This Release)* | **Production Stable** | **Pure HID keyboard firmware.** Corrected USB enumeration order, integrated Microchip VID/PID (`0x04D8:0xE417`), differential report dispatching, and removed CLI/MIDI complexity. |
| **v1.3 RC3 / v1.4** | Feature Branch | Advanced build with simultaneous HID + MIDI, Serial CLI, flash settings, and custom `board integration for Arduino IDE. |

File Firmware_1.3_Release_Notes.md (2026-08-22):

# VE7GGH CW Adapter Firmware v1.3 Release Notes

## Overview

Firmware v1.3 is the stable USB HID release for the **VE7GGH CW Adapter**. It is intended for use with the custom VE7GGH UF2 bootloader on ATSAMD21E18A-based hardware.

This release concentrates on a focused CW paddle interface: it reads Dit and Dah contacts from the TRRS jack and presents them to the host as USB keyboard modifiers. Unlike the separate feature-development release-candidate branch, v1.3 does **not** include USB MIDI, a serial command-line interface, or flash-stored user settings.

## New in v1.3

- Sets the application USB Vendor ID and Product ID to match the custom bootloader:
  - Vendor ID: `0x04D8`
  - Product ID: `0xE417`
- Sets application USB descriptors to:
  - Manufacturer: `VE7GGH`
  - Product: `VE7GGH CW Adapter`
- Performs a TinyUSB detach/attach cycle after applying the USB identity so the host can re-enumerate the device with the intended identifiers.
- Establishes v1.3 as the stable, HID-only firmware line for the CW Adapter.

## HID Paddle Operation

- **Dit** (`PIN_TIP`) sends `Left Ctrl`.
- **Dah** (`PIN_RING1`) sends `Right Ctrl`.
- Pressing both contacts sends both modifier states together.
- Paddle inputs use internal pull-up resistors; a contact is active when pulled LOW.
- The firmware checks that the HID interface is ready before sending keyboard reports.

## Hardware and Visual Feedback

- Supports the ATSAMD21E18A-based VE7GGH CW Adapter hardware.
- Maintains TRS plug compatibility by driving both ground-related jack contacts LOW:
  - `PIN_RING2`
  - `PIN_SLEEVE`
- NeoPixel status colors:
  - Idle: dim blue
  - Dit active: green
  - Dah active: amber
  - Both active: purple
- Provides a white startup confirmation flash after USB mounting.

## USB Identity and Licensing

This release uses the following USB identity:

| Field | Value |
| :--- | :--- |
| Vendor ID | `0x04D8` |
| Product ID | `0xE417` |
| Manufacturer | `VE7GGH` |
| Product | `VE7GGH CW Adapter` |

The VID/PID assignment is used under the project's limited Microchip USB licensing arrangement for SAMD-based products, with a total production limit of **10,000 units**. Distribution and production should remain within the terms of that arrangement.

## Bootloader Compatibility

Firmware v1.3 is intended for the custom VE7GGH UF2 bootloader with the following known configuration:

- Product name: `VE7GGH CW Adapter`
- UF2 volume label: `CWUSBUPDATE`
- Board ID: `SAMD21E18A-CWUSB-v1`
- USB VID/PID: `0x04D8:0xE417`

## Not Included in This Stable Release

The following capabilities are intentionally not part of the v1.3 stable HID firmware:

- USB MIDI paddle output
- Serial CLI configuration commands
- User-configurable MIDI notes or operating modes
- Flash-persistent settings

These remain separate feature-branch capabilities and are not required for standard HID CW keying.

## Upgrade Instructions

1. Connect the CW Adapter to the computer.
2. Double-press the RESET button to enter UF2 bootloader mode.
3. Wait for the `CWUSBUPDATE` drive to appear.
4. Drag and drop the v1.3 firmware `.uf2` file onto the drive.
5. Wait for the device to reboot automatically into the updated firmware.

## Compatibility

- ATSAMD21E18A
- VE7GGH CW Adapter hardware
- Custom VE7GGH UF2 bootloader
- TinyUSB HID keyboard stack
- Windows, Linux, and macOS hosts

## Known Issues

- None currently identified for the HID-only v1.3 release.

Thank you to everyone who tested and provided feedback during development.

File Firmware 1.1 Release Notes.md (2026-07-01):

# VE7GGH CW Adapter Firmware v1.1 Release Notes

Release Date: June 2026

## Overview

Firmware v1.1 is the first public release intended for use with the custom VE7GGH UF2 bootloader. This release focuses on improving usability, branding, and deployment while maintaining compatibility with the ATSAMD21E18A hardware platform.

## New Features

- Compatible with the custom VE7GGH UF2 bootloader.
- Supports drag-and-drop firmware updates using the UF2 bootloader.
- Full USB HID keyboard operation.
- Updated device branding to "VE7GGH CW Adapter."

## Improvements

- Improved compatibility with the custom bootloader.
- Updated project documentation.
- Standardized firmware build process.
- Improved support for future firmware updates through the UF2 bootloader.

## Bootloader Compatibility

This firmware is intended for use with the VE7GGH custom bootloader featuring:

- Product Name: VE7GGH CW Adapter
- UF2 Volume Label: CWUSBUPDATE
- Board ID: SAMD21E18A-CWUSB-v1

## Fixed

- Improved reliability of firmware deployment using UF2.
- Updated project identification strings.
- Corrected project URL embedded in bootloader metadata.

## Known Issues

- None currently identified.

## Upgrade Instructions

1. Connect the CW Adapter to the computer.
2. Double-press the RESET button to enter UF2 bootloader mode.
3. Wait for the `CWUSBUPDATE` drive to appear.
4. Drag and drop the new firmware `.uf2` file onto the drive.
5. The device will automatically reboot into the updated firmware.

## Compatibility

- ATSAMD21E18A
- Custom VE7GGH CW Adapter hardware
- Custom VE7GGH UF2 Bootloader
- Windows, Linux, and macOS

Thank you to everyone who tested and provided feedback during development.

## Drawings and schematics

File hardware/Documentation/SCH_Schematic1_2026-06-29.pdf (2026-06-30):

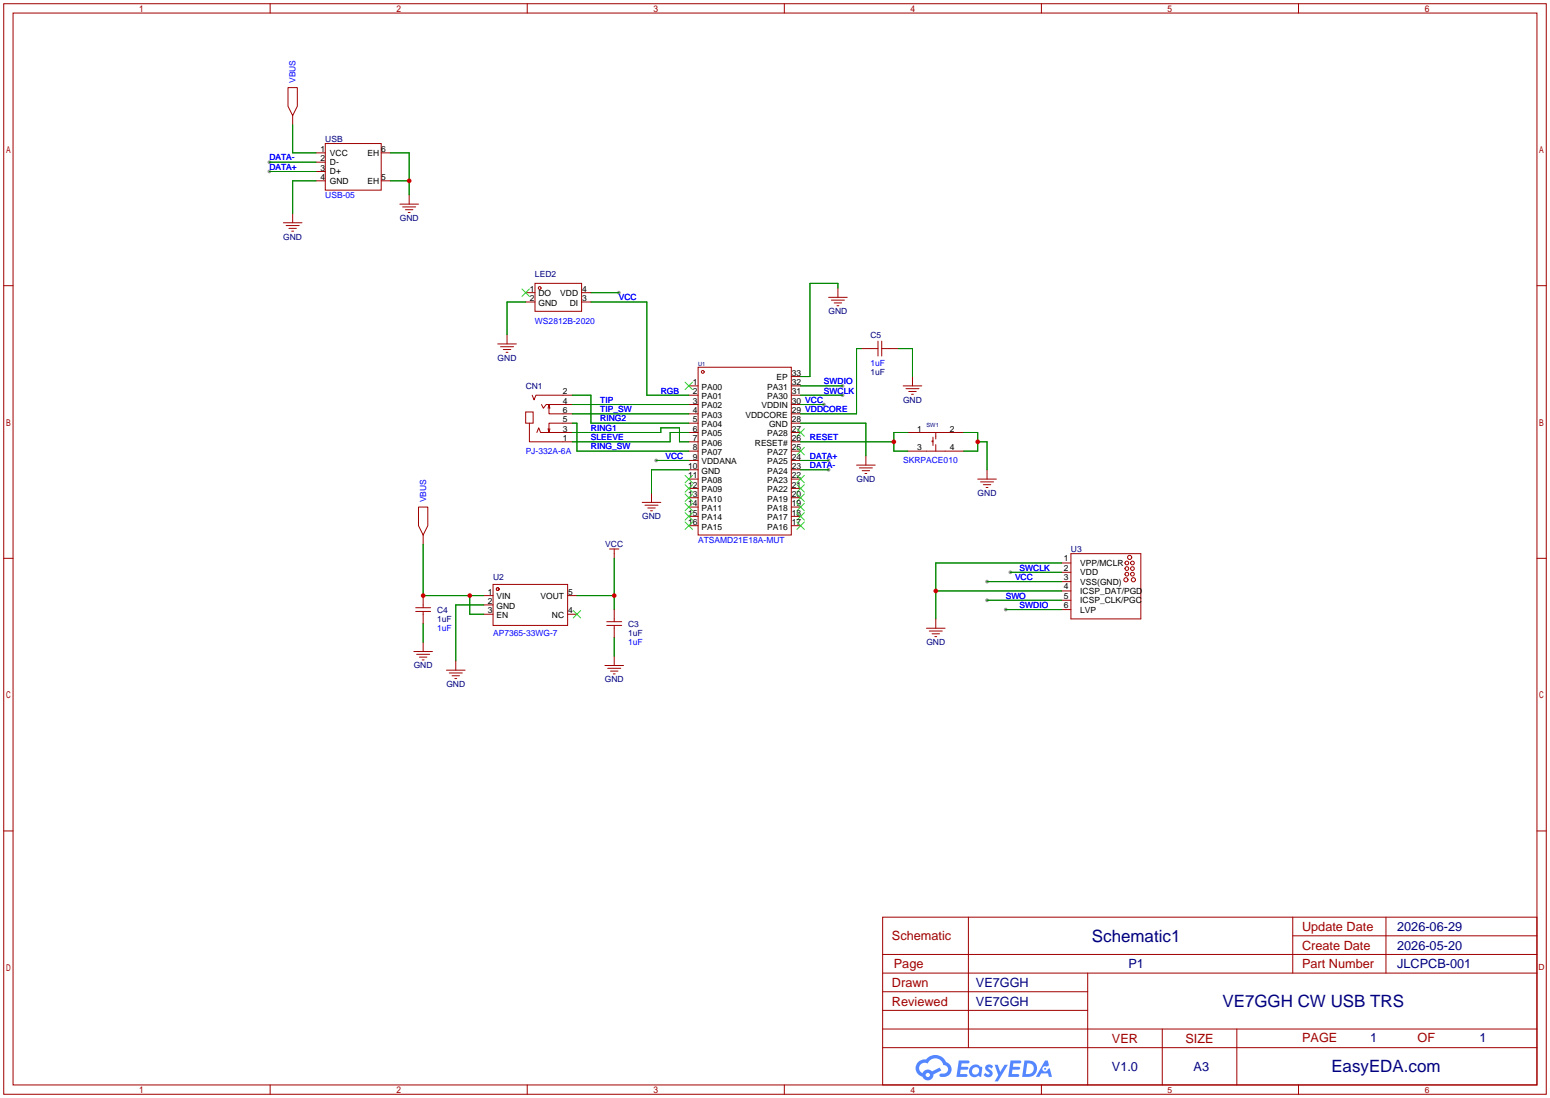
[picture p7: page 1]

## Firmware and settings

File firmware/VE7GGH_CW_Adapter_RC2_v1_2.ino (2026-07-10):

/*
  VE7GGH CW USB Adapter
  Firmware Version: 1.2 RC2

  Author:   VE7GGH
  Project:  CW USB Adapter
  GitHub:   https://github.com/ve7ggh/CW-USB-Adatper-1.1
  License:  See LICENSE.md in project repository

  Description:
    Open-source USB CW paddle interface firmware.
    Converts a standard 3.5mm TRS iambic CW paddle into a USB HID keyboard
    and/or USB MIDI device. No drivers required.

  Features:
    - USB HID Keyboard: Left Ctrl (Dit) / Right Ctrl (Dah)
    - USB MIDI Device: Note On/Off for Dit/Dah (default notes 20/21)
    - Three operating modes: HID Only, MIDI Only, HID + MIDI
    - Serial CLI for real-time configuration
    - Flash persistence: mode and MIDI notes survive power cycles
    - Onboard RGB NeoPixel status indicator

  Compatible software:
    - Morse Code World, VBand, DitDahDit, and any CW keyboard app (HID mode)
    - FlexRadio / NetKeyer (MIDI mode)

  Hardware:
    - Microchip ATSAMD21E18A MCU
    - USB 2.0 Full-Speed Native USB
    - 3.5mm TRS paddle input
    - RGB NeoPixel status LED
    - UF2 drag-and-drop firmware updates

  Build Requirements:
    - Arduino IDE with Adafruit SAMD board package
    - Tools > USB Stack: TinyUSB
    - Libraries: Adafruit NeoPixel, Adafruit TinyUSB, FlashStorage_SAMD (v1.3.2+)

  Serial CLI Commands:
    help                       Show available commands
    status                     Show mode, paddle state, MIDI notes
    mode [hid|midi|both]       Set operating mode (type 'save' to persist)
    midi_notes                 Show current MIDI note assignments
    set_notes <dit> <dah>      Set MIDI notes 0-127 (type 'save' to persist)
    save                       Save current settings to flash
    reset                      Restore factory defaults and save

  Firmware Update:
    1. Double-tap the Reset button
    2. A USB drive will appear on the host
    3. Drag the new .uf2 file onto the drive
    4. Device reboots automatically

  This is an independent open-source project.
  Not affiliated with, sponsored by, or endorsed by Adafruit Industries.

  Canadian-designed open-source ham radio project.
  73 de VE7GGH
*/
#define USB_MANUFACTURER "VE7GGH"
#define USB_PRODUCT      "CW USB Adapter"
#include <Adafruit_NeoPixel.h>
#include "Adafruit_TinyUSB.h"
#include <FlashStorage_SAMD.h>

// Hardware pins
#define NEOPIXEL_PIN    PIN_NEOPIXEL
#define NEOPIXEL_COUNT  1
#define DIT_PIN         PIN_TIP
#define DAH_PIN         PIN_RING1
#define GND_COMP_PIN    PIN_RING2
#define GND_MAIN_PIN    PIN_SLEEVE

// Factory defaults
#define DEFAULT_DIT_NOTE  20
#define DEFAULT_DAH_NOTE  21
#define DEFAULT_MODE      2     // MODE_BOTH

// USB HID keyboard modifier mappings
#define DIT_MODIFIER  KEYBOARD_MODIFIER_LEFTCTRL
#define DAH_MODIFIER  KEYBOARD_MODIFIER_RIGHTCTRL

// Operating modes
enum OperatingMode { MODE_HID_ONLY = 0, MODE_MIDI_ONLY = 1, MODE_BOTH = 2 };

// Persisted settings structure
typedef struct {
  boolean valid;
  uint8_t ditNote;
  uint8_t dahNote;
  uint8_t mode;
} Settings;

FlashStorage(flash_store, Settings);

// Peripherals
Adafruit_NeoPixel pixel(NEOPIXEL_COUNT, NEOPIXEL_PIN, NEO_GRB + NEO_KHZ800);

const uint8_t desc_hid_report[] = { TUD_HID_REPORT_DESC_KEYBOARD() };
Adafruit_USBD_HID  usb_hid(desc_hid_report, sizeof(desc_hid_report), HID_ITF_PROTOCOL_KEYBOARD, 2, false);
Adafruit_USBD_MIDI usb_midi;

// Runtime state
OperatingMode currentMode = (OperatingMode)DEFAULT_MODE;
uint8_t       ditNote     = DEFAULT_DIT_NOTE;
uint8_t       dahNote     = DEFAULT_DAH_NOTE;
bool          prevDit     = false;
bool          prevDah     = false;

// Forward declarations
void loadSettings();
void saveSettings();
void resetSettings();
void handleHID(bool dit, bool dah);
void handleMIDI(bool dit, bool dah);
void sendNoteOn(uint8_t ch, uint8_t note, uint8_t vel);
void sendNoteOff(uint8_t ch, uint8_t note, uint8_t vel);
void updatePixel(bool dit, bool dah);
void flashPixel(uint32_t color, int times, int ms);
void handleSerial();
void printWelcome();
void printStatus();

void setup() {
  pinMode(DIT_PIN,      INPUT_PULLUP);
  pinMode(DAH_PIN,      INPUT_PULLUP);
  pinMode(GND_COMP_PIN, OUTPUT);
  pinMode(GND_MAIN_PIN, OUTPUT);
  digitalWrite(GND_COMP_PIN, LOW);
  digitalWrite(GND_MAIN_PIN, LOW);

  
  usb_hid.begin();
  usb_midi.begin();

  pixel.begin();
  pixel.setBrightness(80);
  pixel.setPixelColor(0, pixel.Color(0, 0, 20));
  pixel.show();

  Serial.begin(115200);
  unsigned long t = millis();
  while (!Serial && (millis() - t < 2000)) delay(1);
  while (!TinyUSBDevice.mounted()) delay(1);

  loadSettings();

  // Startup: white double-flash
  flashPixel(pixel.Color(80, 80, 80), 2, 150);
  pixel.setPixelColor(0, pixel.Color(0, 0, 20));
  pixel.show();

  printWelcome();
  printStatus();
}

void loop() {
  bool dit = (digitalRead(DIT_PIN) == LOW);
  bool dah = (digitalRead(DAH_PIN) == LOW);

  if (currentMode == MODE_HID_ONLY  || currentMode == MODE_BOTH) handleHID(dit, dah);
  if (currentMode == MODE_MIDI_ONLY || currentMode == MODE_BOTH) handleMIDI(dit, dah);

  updatePixel(dit, dah);
  handleSerial();

  prevDit = dit;
  prevDah = dah;
  delay(5);
}

// FIX: FlashStorage_SAMD requires read(T &data) — pass struct by reference
void loadSettings() {
  Settings s;
  flash_store.read(s);
  if (s.valid) {
    currentMode = (OperatingMode)constrain(s.mode, 0, 2);
    ditNote     = (uint8_t)constrain(s.ditNote, 0, 127);
    dahNote     = (uint8_t)constrain(s.dahNote, 0, 127);
    Serial.println("Settings loaded from flash.");
  } else {
    currentMode = (OperatingMode)DEFAULT_MODE;
    ditNote     = DEFAULT_DIT_NOTE;
    dahNote     = DEFAULT_DAH_NOTE;
    Serial.println("No saved settings. Using factory defaults.");
  }
}

void saveSettings() {
  Settings s;
  s.valid   = true;
  s.mode    = (uint8_t)currentMode;
  s.ditNote = ditNote;
  s.dahNote = dahNote;
  flash_store.write(s);
  Serial.println("Settings saved to flash.");
  flashPixel(pixel.Color(0, 80, 80), 3, 100);
  pixel.setPixelColor(0, pixel.Color(0, 0, 20));
  pixel.show();
}

void resetSettings() {
  currentMode = (OperatingMode)DEFAULT_MODE;
  ditNote     = DEFAULT_DIT_NOTE;
  dahNote     = DEFAULT_DAH_NOTE;
  saveSettings();
  Serial.println("Factory defaults restored and saved.");
}

void handleHID(bool dit, bool dah) {
  uint8_t mod = 0;
  if (dit) mod |= DIT_MODIFIER;
  if (dah) mod |= DAH_MODIFIER;
  uint8_t keys[6] = {0};
  usb_hid.keyboardReport(0, mod, keys);
}

void sendNoteOn(uint8_t ch, uint8_t note, uint8_t vel) {
  uint8_t packet[4];
  packet[0] = 0x09;
  packet[1] = 0x90 | (ch & 0x0F);
  packet[2] = note & 0x7F;
  packet[3] = vel  & 0x7F;
  usb_midi.write(packet, 4);
}

void sendNoteOff(uint8_t ch, uint8_t note, uint8_t vel) {
  uint8_t packet[4];
  packet[0] = 0x08;
  packet[1] = 0x80 | (ch & 0x0F);
  packet[2] = note & 0x7F;
  packet[3] = vel  & 0x7F;
  usb_midi.write(packet, 4);
}

void handleMIDI(bool dit, bool dah) {
  if ( dit && !prevDit) sendNoteOn (0, ditNote, 127);
  if (!dit &&  prevDit) sendNoteOff(0, ditNote, 0);
  if ( dah && !prevDah) sendNoteOn (0, dahNote, 127);
  if (!dah &&  prevDah) sendNoteOff(0, dahNote, 0);
}

void updatePixel(bool dit, bool dah) {
  uint32_t color;
  if      (dit && dah) color = pixel.Color(80,  0,  80);
  else if (dit)        color = pixel.Color(0,  80,   0);
  else if (dah)        color = pixel.Color(80, 40,   0);
  else                 color = pixel.Color(0,   0,  20);
  pixel.setPixelColor(0, color);
  pixel.show();
}

void flashPixel(uint32_t color, int times, int ms) {
  for (int i = 0; i < times; i++) {
    pixel.setPixelColor(0, color);
    pixel.show();
    delay(ms);
    pixel.setPixelColor(0, 0);
    pixel.show();
    delay(ms);
  }
}

void printStatus() {
  const char* modeStr = (currentMode == MODE_HID_ONLY)  ? "HID Only"  :
                        (currentMode == MODE_MIDI_ONLY) ? "MIDI Only" : "HID + MIDI";
  Serial.print("Mode     : "); Serial.println(modeStr);
  Serial.print("DIT note : "); Serial.println(ditNote);
  Serial.print("DAH note : "); Serial.println(dahNote);
  Serial.print("DIT pin  : "); Serial.println(digitalRead(DIT_PIN) == LOW ? "active" : "inactive");
  Serial.print("DAH pin  : "); Serial.println(digitalRead(DAH_PIN) == LOW ? "active" : "inactive");
}

void handleSerial() {
  if (!Serial.available()) return;

  String line = Serial.readStringUntil('\n');
  line.trim();
  if (line.length() == 0) return;

  String cmd = line;
  cmd.toLowerCase();

  if (cmd == "help") {
    Serial.println("----------------------------------------");
    Serial.println("  VE7GGH CW USB Adapter - Firmware 1.2");
    Serial.println("  github.com/ve7ggh/CW-USB-Adatper-1.1");
    Serial.println("Commands:");
    Serial.println("  help");
    Serial.println("  status");
    Serial.println("  mode [hid|midi|both]");
    Serial.println("  midi_notes");
    Serial.println("  set_notes <dit> <dah>   (0-127)");
    Serial.println("  save");
    Serial.println("  reset");
    Serial.println("----------------------------------------");
  } else if (cmd == "status") {
    printStatus();
  } else if (cmd.startsWith("mode ")) {
    String arg = cmd.substring(5);
    arg.trim();
    if      (arg == "hid")  { currentMode = MODE_HID_ONLY;  Serial.println("Mode: HID Only (type 'save' to persist)"); }
    else if (arg == "midi") { currentMode = MODE_MIDI_ONLY; Serial.println("Mode: MIDI Only (type 'save' to persist)"); }
    else if (arg == "both") { currentMode = MODE_BOTH;      Serial.println("Mode: HID + MIDI (type 'save' to persist)"); }
    else Serial.println("Unknown mode. Use: hid, midi, both");
  } else if (cmd == "midi_notes") {
    Serial.print("DIT note: "); Serial.println(ditNote);
    Serial.print("DAH note: "); Serial.println(dahNote);
  } else if (cmd.startsWith("set_notes ")) {
    String rest = cmd.substring(10);
    rest.trim();
    int sp = rest.indexOf(' ');
    if (sp <= 0) {
      Serial.println("Usage: set_notes <dit> <dah>");
    } else {
      int nd = rest.substring(0, sp).toInt();
      int nh = rest.substring(sp + 1).toInt();
      if (nd < 0 || nd > 127 || nh < 0 || nh > 127) {
        Serial.println("Notes must be 0-127");
      } else {
        ditNote = (uint8_t)nd;
        dahNote = (uint8_t)nh;
        Serial.print("DIT note: "); Serial.println(ditNote);
        Serial.print("DAH note: "); Serial.println(dahNote);
        Serial.println("(type 'save' to persist)");
      }
    }
  } else if (cmd == "save") {
    saveSettings();
  } else if (cmd == "reset") {
    resetSettings();
    printStatus();
  } else {
    Serial.println("Unknown command. Type 'help'");
  }
}

void printWelcome() {
  Serial.println();
  Serial.println("========================================");
  Serial.println("   VE7GGH CW USB Adapter  |  FW 1.2   ");
  Serial.println("   Open Source CW Paddle Interface     ");
  Serial.println("   github.com/ve7ggh/CW-USB-Adatper-1.1");
  Serial.println("   Type 'help' for commands            ");
  Serial.println("========================================");
  Serial.println();
}

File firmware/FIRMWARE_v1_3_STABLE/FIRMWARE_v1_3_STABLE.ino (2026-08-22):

/*
 ====
 *  VE7GGH CW USB Adapter — Pure HID Keyboard Interface (v1.3 Stable)
 * ====
 *  Author      : VE7GGH
 *  License     : MIT License (Open Source)
 *  Hardware    : VE7GGH CW USB Adapter (SAMD21E18A)
 *  IDE         : Arduino IDE 1.8.13+ / 2.x
 *  USB Stack   : TinyUSB (Tools > USB Stack > TinyUSB)
 *  VID / PID   : 0x04D8 : 0xE417 (Sublicensed via Microchip Application)
 *  73 de VE7GGH!
 *
 *  Description :
 *    Dedicated, ultra-low-latency USB HID keyboard adapter for CW iambic paddles.
 *    Translates paddle Dit and Dah contacts into Left Ctrl (Dit) and Right Ctrl (Dah)
 *    modifier keypresses for CW keyer software (e.g., Morse Runner, VBand, web keyers).
 *
 *    TRS/TRRS Compatibility:
 *    A standard 3.5mm TRS stereo plug inserted into the TRRS jack grounds both
 *    PIN_RING2 and PIN_SLEEVE, ensuring clean ground reference.
 *
 *  Pin Mapping :
 *    DIT  (Tip)    -> PIN_TIP    (GPIO 0) -> Left Ctrl
 *    DAH  (Ring 1) -> PIN_RING1  (GPIO 2) -> Right Ctrl
 *    GND  (Ring 2) -> PIN_RING2  (GPIO 4) -> Output LOW (TRS compatibility)
 *    GND  (Sleeve) -> PIN_SLEEVE (GPIO 5) -> Output LOW
 *
 *  NeoPixel Feedback :
 *    Idle        -> Dim Blue
 *    Dit Active  -> Green
 *    Dah Active  -> Amber
 *    Both Active -> Purple
 *
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
 *    THE SOFTWARE IS PROVIDED "AS IS", WITHOUT WARRANTY OF ANY KIND, EXPRESS OR
 *    IMPLIED, INCLUDING BUT NOT LIMITED TO THE WARRANTIES OF MERCHANTABILITY,
 *    FITNESS FOR A PARTICULAR PURPOSE AND NONINFRINGEMENT. IN NO EVENT SHALL THE
 *    AUTHORS OR COPYRIGHT HOLDERS BE LIABLE FOR ANY CLAIM, DAMAGES OR OTHER
 *    LIABILITY, WHETHER IN AN ACTION OF CONTRACT, TORT OR OTHERWISE, ARISING FROM,
 *    OUT OF OR IN CONNECTION WITH THE SOFTWARE OR THE USE OR OTHER DEALINGS IN
 *    THE SOFTWARE.
 * ====
 */





#include <Adafruit_NeoPixel.h>
#include "Adafruit_TinyUSB.h"

// ── USB Identification (must match bootloader/board_config.h) ────
#define USB_VID 0x04D8
#define USB_PID 0xE417

// ── Hardware ────
#define NEOPIXEL_PIN    PIN_NEOPIXEL
#define NEOPIXEL_COUNT  1

// Pin mapping based on your diagnostic results
#define DIT_PIN         PIN_TIP     // 0
#define DAH_PIN         PIN_RING1   // 2
#define GND_COMP_PIN    PIN_RING2   // 4 (Extra ground for TRS compatibility)
#define GND_MAIN_PIN    PIN_SLEEVE  // 5

// ── NeoPixel ────
Adafruit_NeoPixel pixel(NEOPIXEL_COUNT, NEOPIXEL_PIN, NEO_GRB + NEO_KHZ800);

// ── TinyUSB HID ────
uint8_t const desc_hid_report[] = { TUD_HID_REPORT_DESC_KEYBOARD() };
Adafruit_USBD_HID usb_hid(desc_hid_report, sizeof(desc_hid_report), HID_ITF_PROTOCOL_KEYBOARD, 2, false);

// ── Colours ────
#define COLOR_IDLE   pixel.Color(0,   0,   20)   // Dim Blue
#define COLOR_DIT    pixel.Color(0,   80,  0)   // Green
#define COLOR_DAH    pixel.Color(80,  40,  0)   // Amber
#define COLOR_BOTH   pixel.Color(80,  0,   80)  // Purple

// ── Key mappings ────
#define DIT_MODIFIER  KEYBOARD_MODIFIER_LEFTCTRL
#define DAH_MODIFIER  KEYBOARD_MODIFIER_RIGHTCTRL

// ── Timing (tune here) ────
#define DEBOUNCE_MS         5     // contact must be stable this long before accepted
#define STUCK_KEY_MS         4000  // auto-release a paddle held longer than this (fail-safe)
#define POLL_INTERVAL_MS     2     // main loop polling interval
#define USB_MOUNT_TIMEOUT_MS  3000  // give up waiting for host enumeration after this long

// ── Runtime state ────
static bool     ditState = false, dahState = false;
static bool     ditLastRaw = false, dahLastRaw = false;
static uint32_t ditChangeT = 0, dahChangeT = 0;
static uint32_t ditHeldSince = 0, dahHeldSince = 0;
static uint32_t lastPoll = 0;
static uint8_t  lastModifier = 0xFF; // force first HID report to be sent

void setup() {
  // Set VID/PID to match bootloader.
  // NOTE: On SAMD cores, TinyUSB auto-starts before setup() runs, so we
  // must force a detach/re-attach for the new ID to actually take effect.
  TinyUSBDevice.setID(USB_VID, USB_PID);
  TinyUSBDevice.setManufacturerDescriptor("VE7GGH");
  TinyUSBDevice.setProductDescriptor("VE7GGH CW Adapter");
  TinyUSBDevice.detach();
  delay(10);
  TinyUSBDevice.attach();

  // Set up paddles with internal pull-ups
  pinMode(DIT_PIN, INPUT_PULLUP);
  pinMode(DAH_PIN, INPUT_PULLUP);

  // Force both potential Ground contacts to LOW
  pinMode(GND_COMP_PIN, OUTPUT);
  digitalWrite(GND_COMP_PIN, LOW);
  pinMode(GND_MAIN_PIN, OUTPUT);
  digitalWrite(GND_MAIN_PIN, LOW);

  usb_hid.begin();

  pixel.begin();
  pixel.setBrightness(80);
  pixel.setPixelColor(0, COLOR_IDLE);
  pixel.show();

  // Wait for USB connection (bounded — avoid hanging forever on enumeration failure)
  uint32_t mountStart = millis();
  while (!TinyUSBDevice.mounted()) {
    if (millis() - mountStart > USB_MOUNT_TIMEOUT_MS) {
      // Enumeration failed/timed out — flash red as an error indicator and continue.
      // (loop() still guards on usb_hid.ready(), so no HID reports are sent until
      // the host actually enumerates the device, even if that happens later.)
      pixel.setPixelColor(0, pixel.Color(80, 0, 0));
      pixel.show();
      delay(150);
      pixel.setPixelColor(0, pixel.Color(0, 0, 0));
      pixel.show();
      delay(150);
      break;
    }
    delay(1);
  }

  // Success indicator flash
  pixel.setPixelColor(0, pixel.Color(80, 80, 80));
  pixel.show();
  delay(300);
  pixel.setPixelColor(0, COLOR_IDLE);
  pixel.show();
}
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

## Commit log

2026-06-30 A TRS compatible USB CW interface with UF2 bootloader
    My first REPO, go easy on me
    I enjoy open source and HAM radio, project born from looking for open and affordable cw paddle adapter.
    Work in progress, new features being worked on.
    Next to add MIDI function for FlexRadio CW key input.
    [BOM_Board1_Schematic1_2026-06-29.xlsx, CW USB Case Top V2.stl, CW USB Case bottom V2.stl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]
2026-08-22 Update README.md
    Added Microchip sublicense VID/PID of 10k units

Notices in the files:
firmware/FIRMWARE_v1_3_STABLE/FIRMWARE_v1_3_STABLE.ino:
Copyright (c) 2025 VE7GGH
